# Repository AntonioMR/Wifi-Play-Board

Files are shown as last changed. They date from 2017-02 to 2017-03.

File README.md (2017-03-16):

# Wifi-Play-Board
Placa de experimentacion para el ESP12F (ESP8266)

## Imagenes
Cara superior
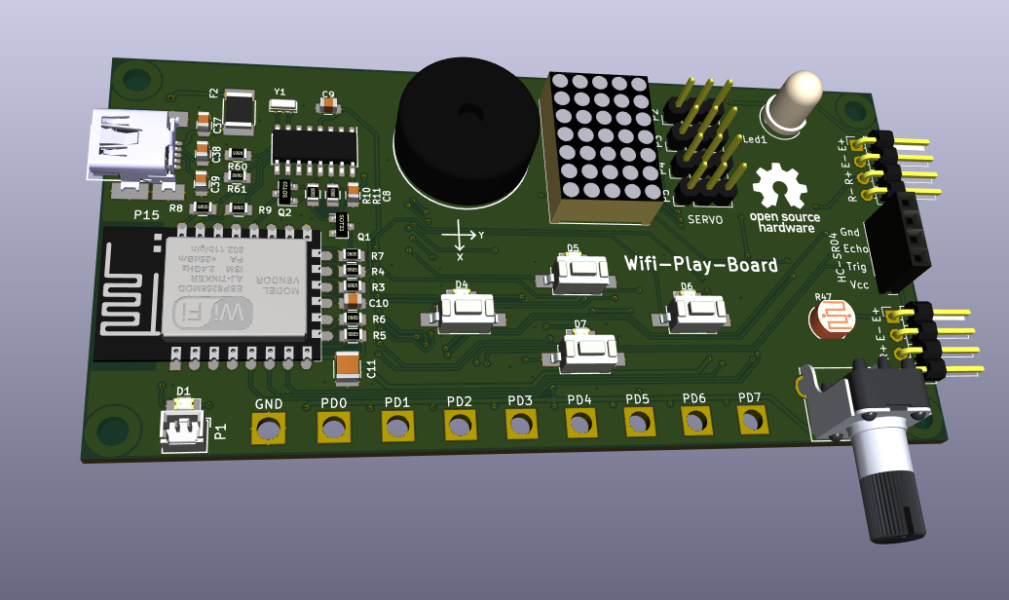
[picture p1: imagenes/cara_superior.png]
Cara superior


Cara inferior
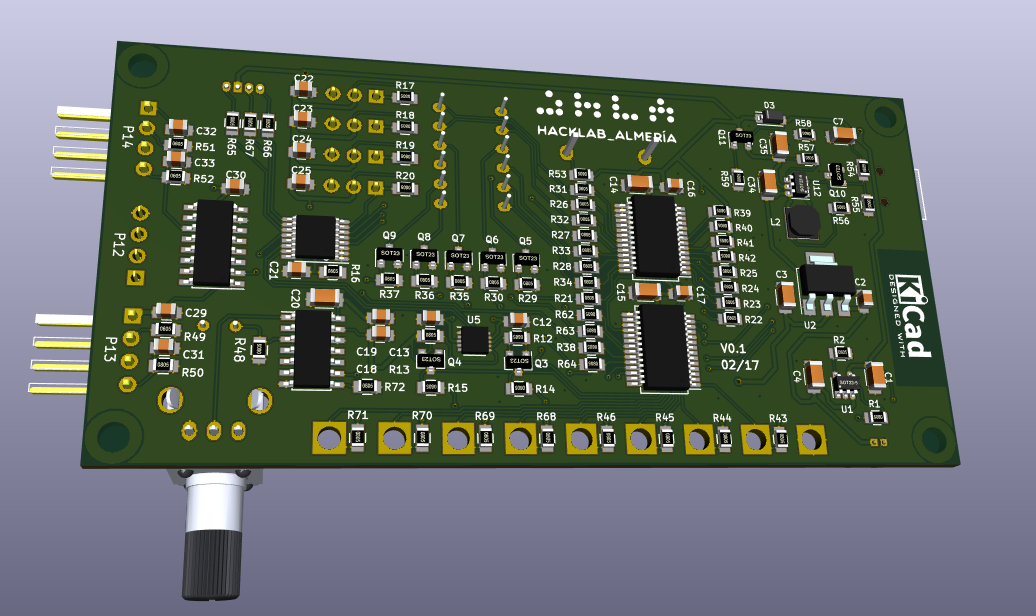
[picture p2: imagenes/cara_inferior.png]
Cara inferior


## Lista de materiales
Refencias | Valor | Total Uds  | Proveedor | ref. Proveedor
----------|-------|------------|-----------|---------------
| R1, R2, R8, R9 | Resistencia 470 Ohm 0805 | 4 | TME | RC0805FR-07470R
| R26, R27, R28, R31, R32, R33, R34, R65, R66, R67 | Resistencia 120 Ohm 0805 | 10 | TME | CRCW0805120RFKTABC
| R38, R49, R51, R62, R63, R64 | Resistencia 220 Ohm 0805 | 6 | TME | RC0805FR-07220R
| R43, R44, R45, R46, R68, R69, R70, R71 | Resistencia 1 MOhm 0805 | 8 | TME | CRCW080510K0FKEA
| R21, R22, R23, R24, R25, R48, R54 | Resistencia 1 KOhm 0805 | 7 | TME | CRCW08051K00FKEA
| R12, R13, R14, R15 | Resistencia 4,7 KOhm 0805 | 4 | TME | CRCW08054K70FKEA
| R29, R30, R35, R36, R37, R50, R52, R55, R72 | Resistencia 47 KOhm 0805 | 9 | TME | CRCW080547K0FKEA
| R10, R11, R16, R17, R18, R19, R20, R3, R39, R4, R40, R41, R42, R5, R53, R56, R59, R6, R7 | Resistencia 10 KOhm 0805 | 19 | TME | CRCW080510K0FKEA
| R60, R61 | Resistencia 22 Ohm 0805 | 2 | TME | CRCW080522R0FKEA
| R57 | Resistencia 976 KOhm 0805 | 1 | RS | 708-7023
| R58 | Resistencia 309 KOhm 0805 | 1 | RS | 708-6871
| C1, C14, C15, C20, C34, C4 | Condensador cerámico 4,7 uF 1206 | 6 | TME | CL31F475ZOFNNNE
| C10 | Condensador cerámico 470 pF 0805 | 1 | TME | CL21B471KBANNND
| C11 | Condensador cerámico 100 uF 1206 | 1 | TME | CL31A107MQHNNNE
| C12, C13, C16, C17, C18, C19, C2, C21, C29, C30, C32, C8, C9 | Condensador cerámico 100 nF 0805 | 13 | TME | CL21B104KBCNNNC
| C22, C23, C24, C25 | Condensador cerámico 1 nF 0805 | 4 | TME | CL21B105KAFNNNE
| C3, C35, C7 | Condensador cerámico 10 uF 1206 | 3 | TME | CL31B103KBCNNNC
| C31, C33, C37 | Condensador cerámico 10 nF 0805 | 3 | TME | CL21B103JBANNNC
| C38, C39 | Condensador cerámico 47 pF 0805 | 2 | TME | CL21C470JBANNNC
| D1, D4, D5, D6, D7 | Diodo LED rojo 0805 | 5 | TME | OSR50805C1E
| D3 | Diodo schottky SOD-123 | 1 | TME | MBR0520L
| F2 | Fusible rearmable 500 mA 1812 | 1 | TME | SD050-16
| L2 | Inductor bobinado 4,7 uH | 1 | RS | 850-7445
| Led1 | LED RGB ánodo común 5mm | 1 | TME | OSTAMA5B31A
| P1 | Conector Molex Picoblade macho recto | 1 | RS | 279-9213
| P13, P14 | Conector Molex Picoblade macho recto | 2 | TME | ZL211-40KG-S
| P15 | Conector USB mini hembra | 1 | TME | MX-67503-1020
| Q1 Q2 Q5 Q6 Q7 Q8 Q9 | Transistor bipolar NPN SOT-23 | 7 | TME | SMBT3904E6327
| Q10 | Transistor bipolar NPN SOT-23 | 1 | TME | BC849CLT1G
| Q11 | Transistor Mosfet P SOT-23 | 1 | TME | NX2301P.215
| Q3, Q4 | Transistor Mosfet P SOT-23 | 1 | TME | BSS138P.215
| BZ1 | Buzzer raster 10 mm | 1 | TME | LD-BZPN-1705
| R47 | Resistencia LDR 5-10 KOhm| 1 | TME | GM4516
| RV1 | Potenciometro lineal 10 KOhm| 1 | RS | 729-3622
| SW1, SW2, SW3, SW4 | Pulsador NO | 4 | TME | DTSM31NB
| U1 | Controlador carga bateria LIPO MCP73831T SOT23-5 | 1 | RS | 738-6617
| U2 | Regulador de tension 3,3V LD1117S33TR SOT23-5 | 1 | RS | LD1117S33TR
| U3 | Conversor USB-Serie CH340G SOIC-16 | 1 |   |
| U5 | Acelerometro 3 ejes MMA7660FC DFN-10 | 1 | RS | 801-6873
| U6, U7 | Expansor GPIO I2C MCP23017 SSOP-28 | 2 | RS | 681-1128
| U8 | Expansor ADC SPI MCP3204 SOIC-14 | 1 | TME | MCP3204-CI/SL
| U9 | Driver para LED 8 canales PCA9551 TSSOP-16 | 1 | RS | 510-730
| U10 | Matriz LED 7x5 Anodo Filas | 1 | TME | KWM-20571ASB
| U11 | Inversor Schmitt trigger | 1 | TME | HEF40106BT
| U12 | Regulador Boost regulable | 1 | RS | 738-6257
| Y1 | Cristal 12 MHHz | 1 | RS | 526-6148

## Licencia
Este diseño es Software Libre; usted puede redistribuirlo y/o modificarlo bajo los términos de la "GNU General Public License" como lo publica la "FSF Free Software Foundation", o (a su elección) de cualquier versión posterior.

Este diseño es distribuido con la esperanza de que le sea útil, pero SIN NINGUNA GARANTIA; incluso sin la garantía implícita por la VENTA o EJERCICIO DE ALGUN PROPOSITO en particular. Vea la "GNU General Public License" para más detalles.

## Creditos
Los modelos 3D de los siguientes componentes están creados a partir de los modelos originales indicados a continuación:

Componente | Autor | Modelo 
-----------|-------|--------
|  |  | 
|  |  | 
|  |  |

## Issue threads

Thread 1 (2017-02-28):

La huella de U11 no corresponde

AntonioMR, 2017-02-28:
En la version V0.1.0 se ha utilizado una huella para SOIC16 cuando el encapsulado es un SOIC14.
En necesario realizar puentes de forma externa para que pueda funcionar esta PCB.
Pendiente de corregir en la siguientes revision

AntonioMR, 2017-03-03:
Corregido en la version V0.1.1

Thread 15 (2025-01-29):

ae:a4:a0:97:82:da need wifi password

Yuhantangonan, 2025-01-29:
ae:a4:a0:97:82:da
Need wifi password

Bahtiar-cyber, 2025-02-11:
da:F1:38:C8:32:0B butuh kata sandinya

valon862, 2025-03-12:
1E:66:32:E7:F0:AD

valon862, 2025-03-12:
> 1E:66:32:E7:F0:AD

Need pasword

Abdullahpunya, 2025-03-22:
2e:16:b4:65:8d:94  Need pasword

ismail690-creator, 2025-04-06:
Butuh kata sandi

ismail690-creator, 2025-04-06:
a8:98:92:3b:42:07 butuh kata sandi

name09651, 2025-04-08:
https://github.com/AntonioMR/Wifi-Play-Board/issues/15

name09651, 2025-04-08:
ae:a4:a0:97:82:da necesito contraseña de wifi #15

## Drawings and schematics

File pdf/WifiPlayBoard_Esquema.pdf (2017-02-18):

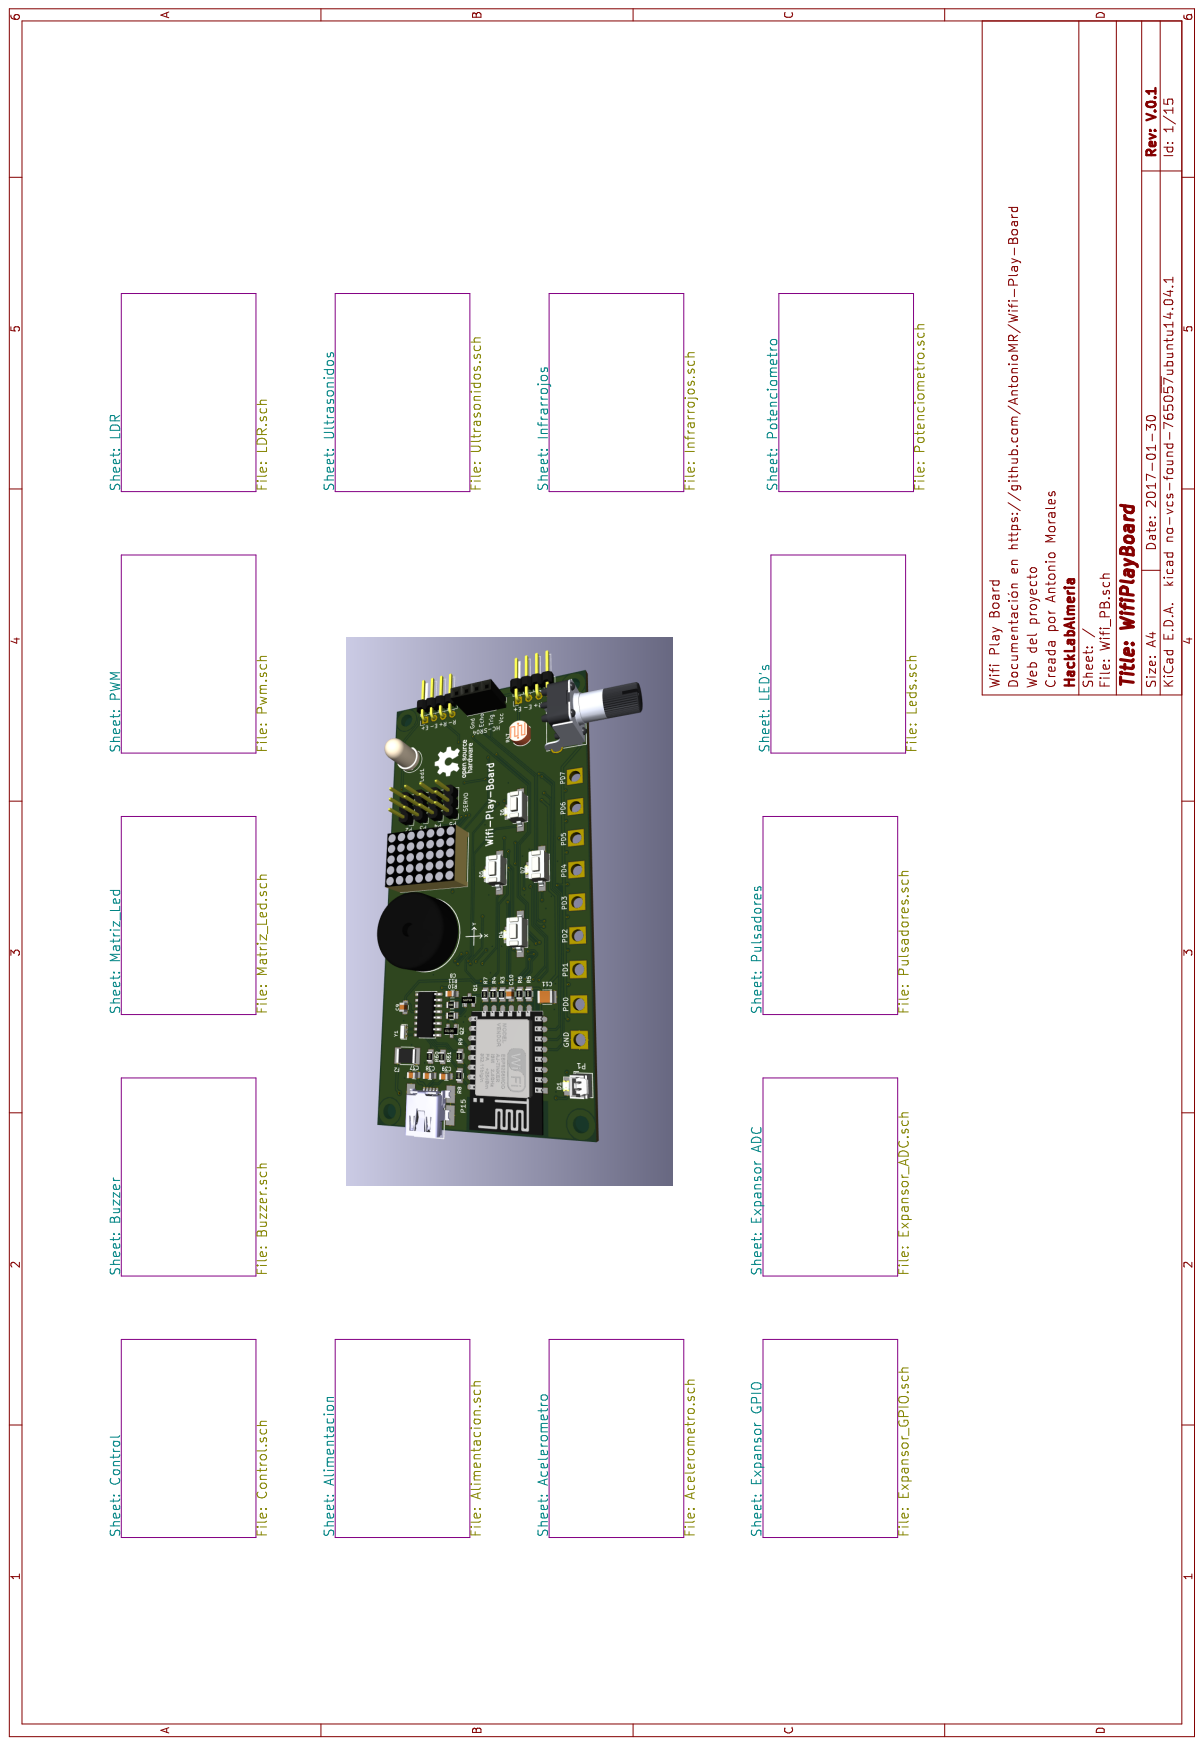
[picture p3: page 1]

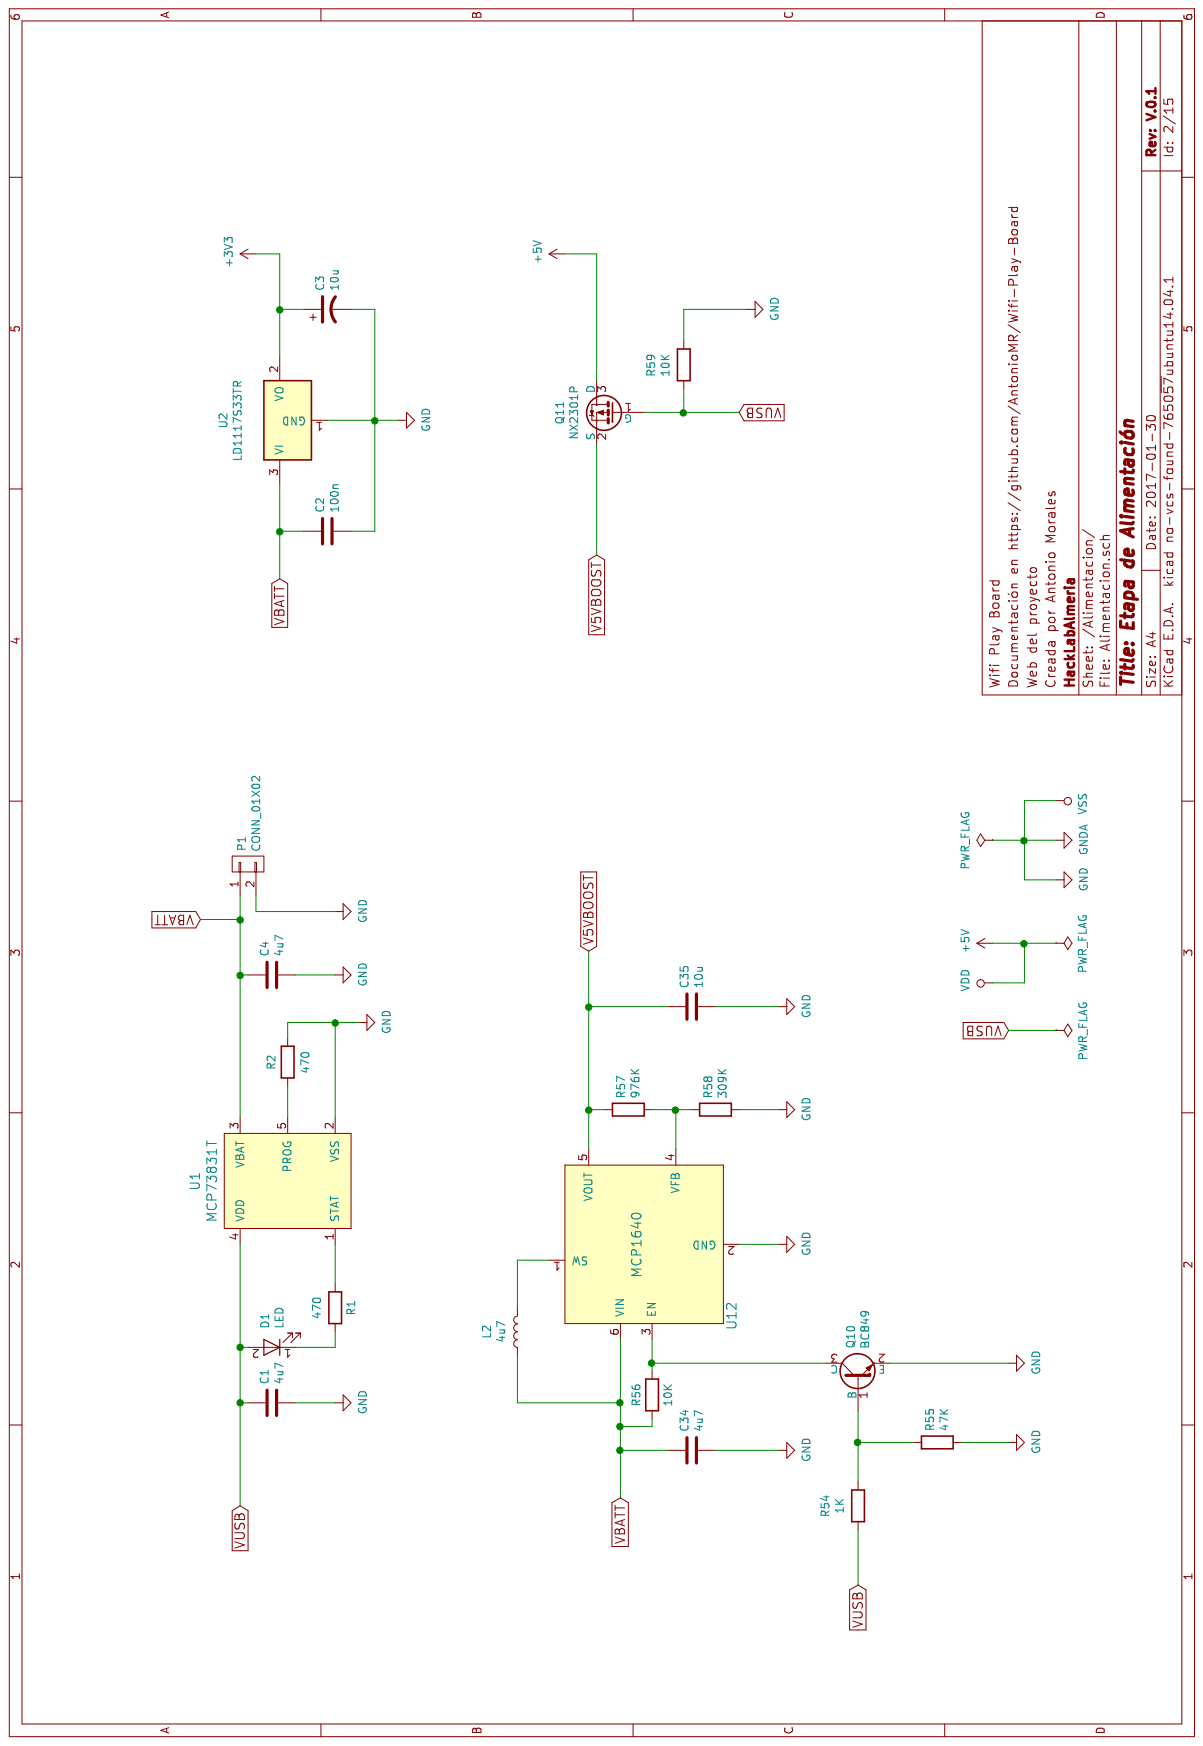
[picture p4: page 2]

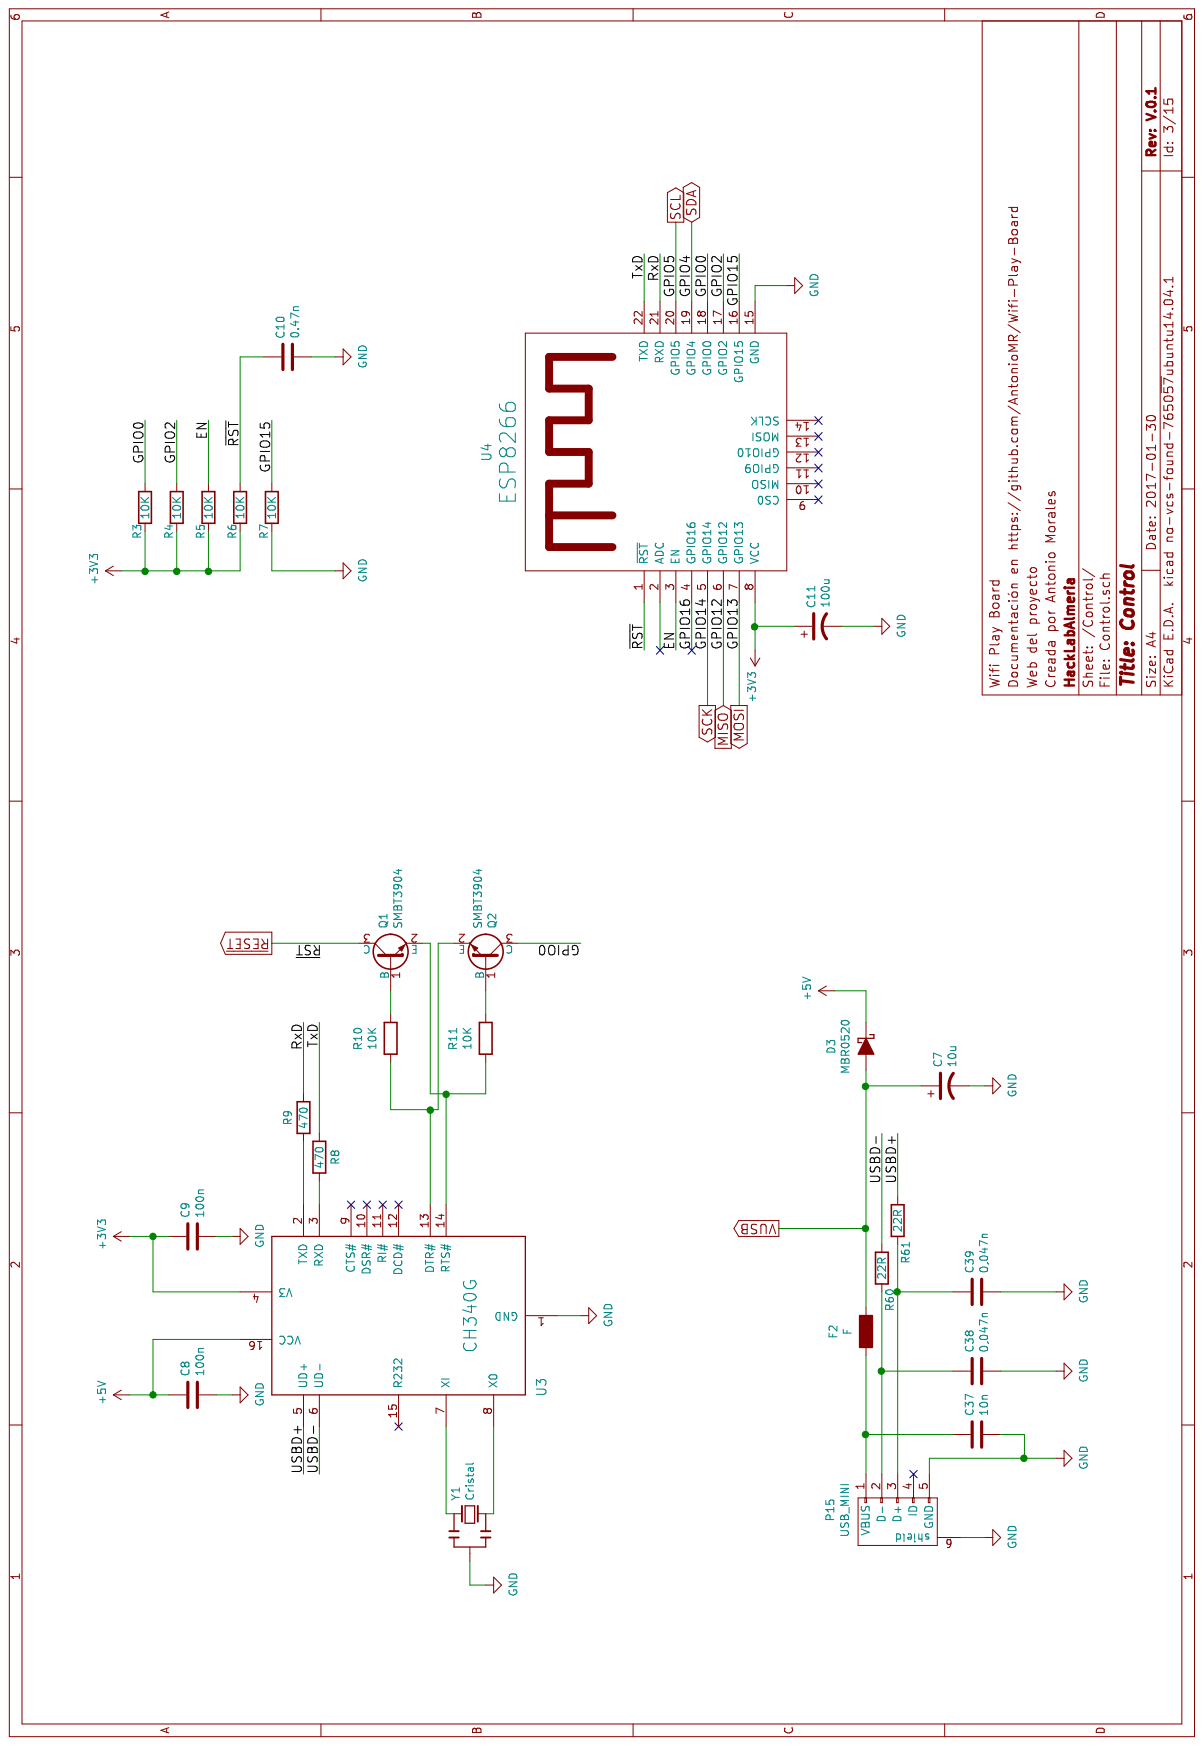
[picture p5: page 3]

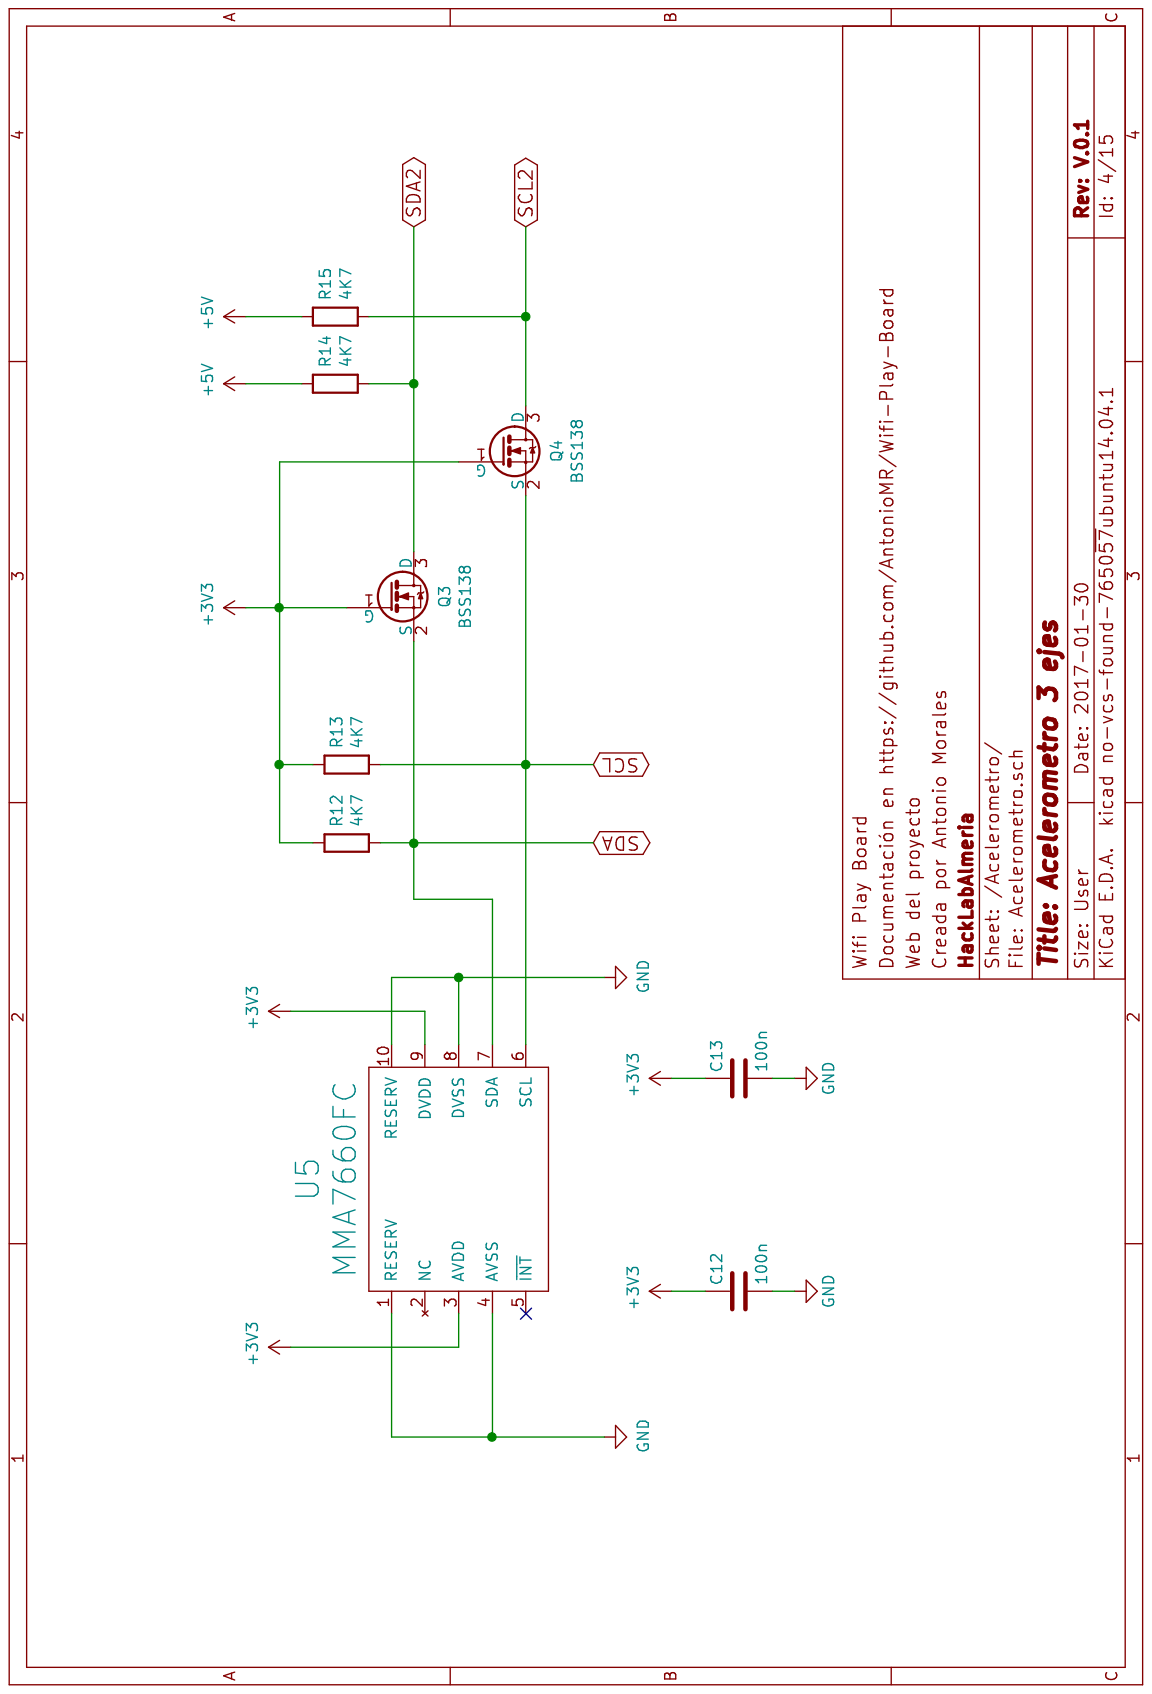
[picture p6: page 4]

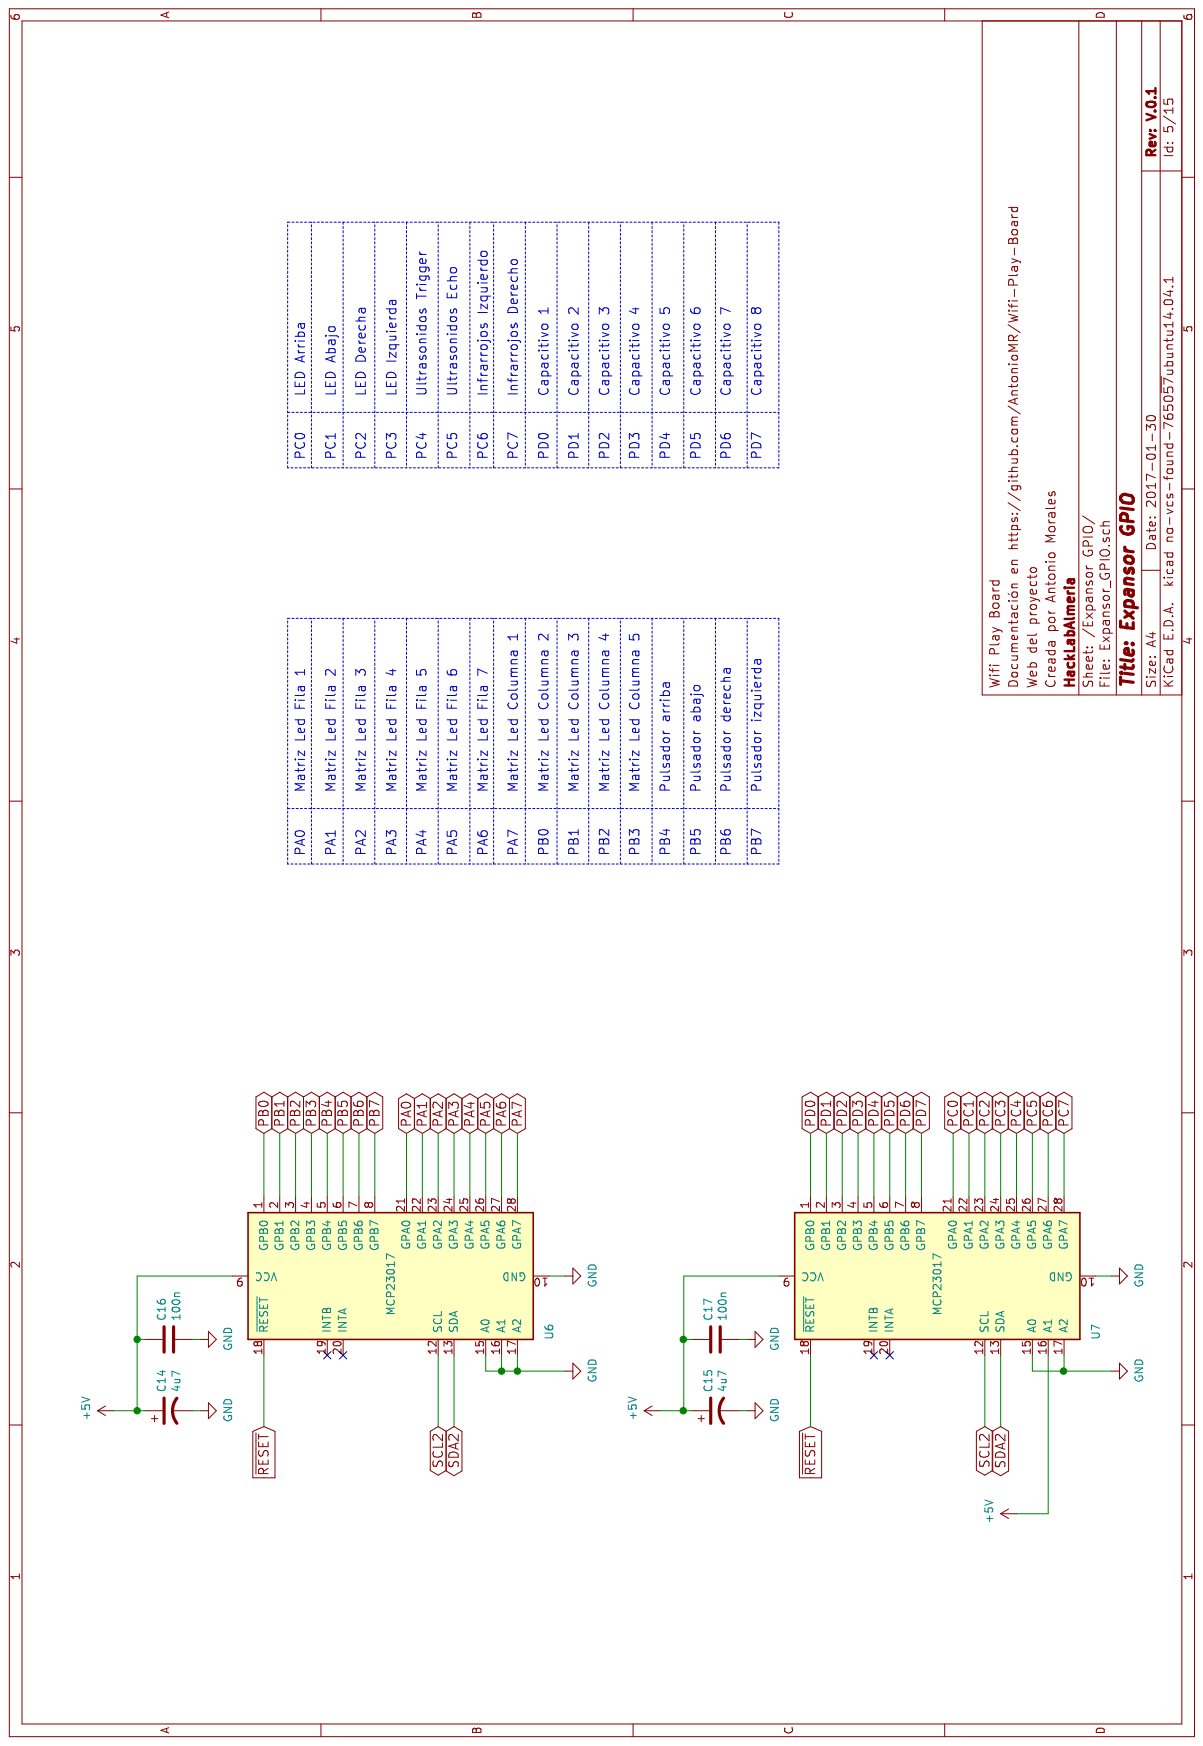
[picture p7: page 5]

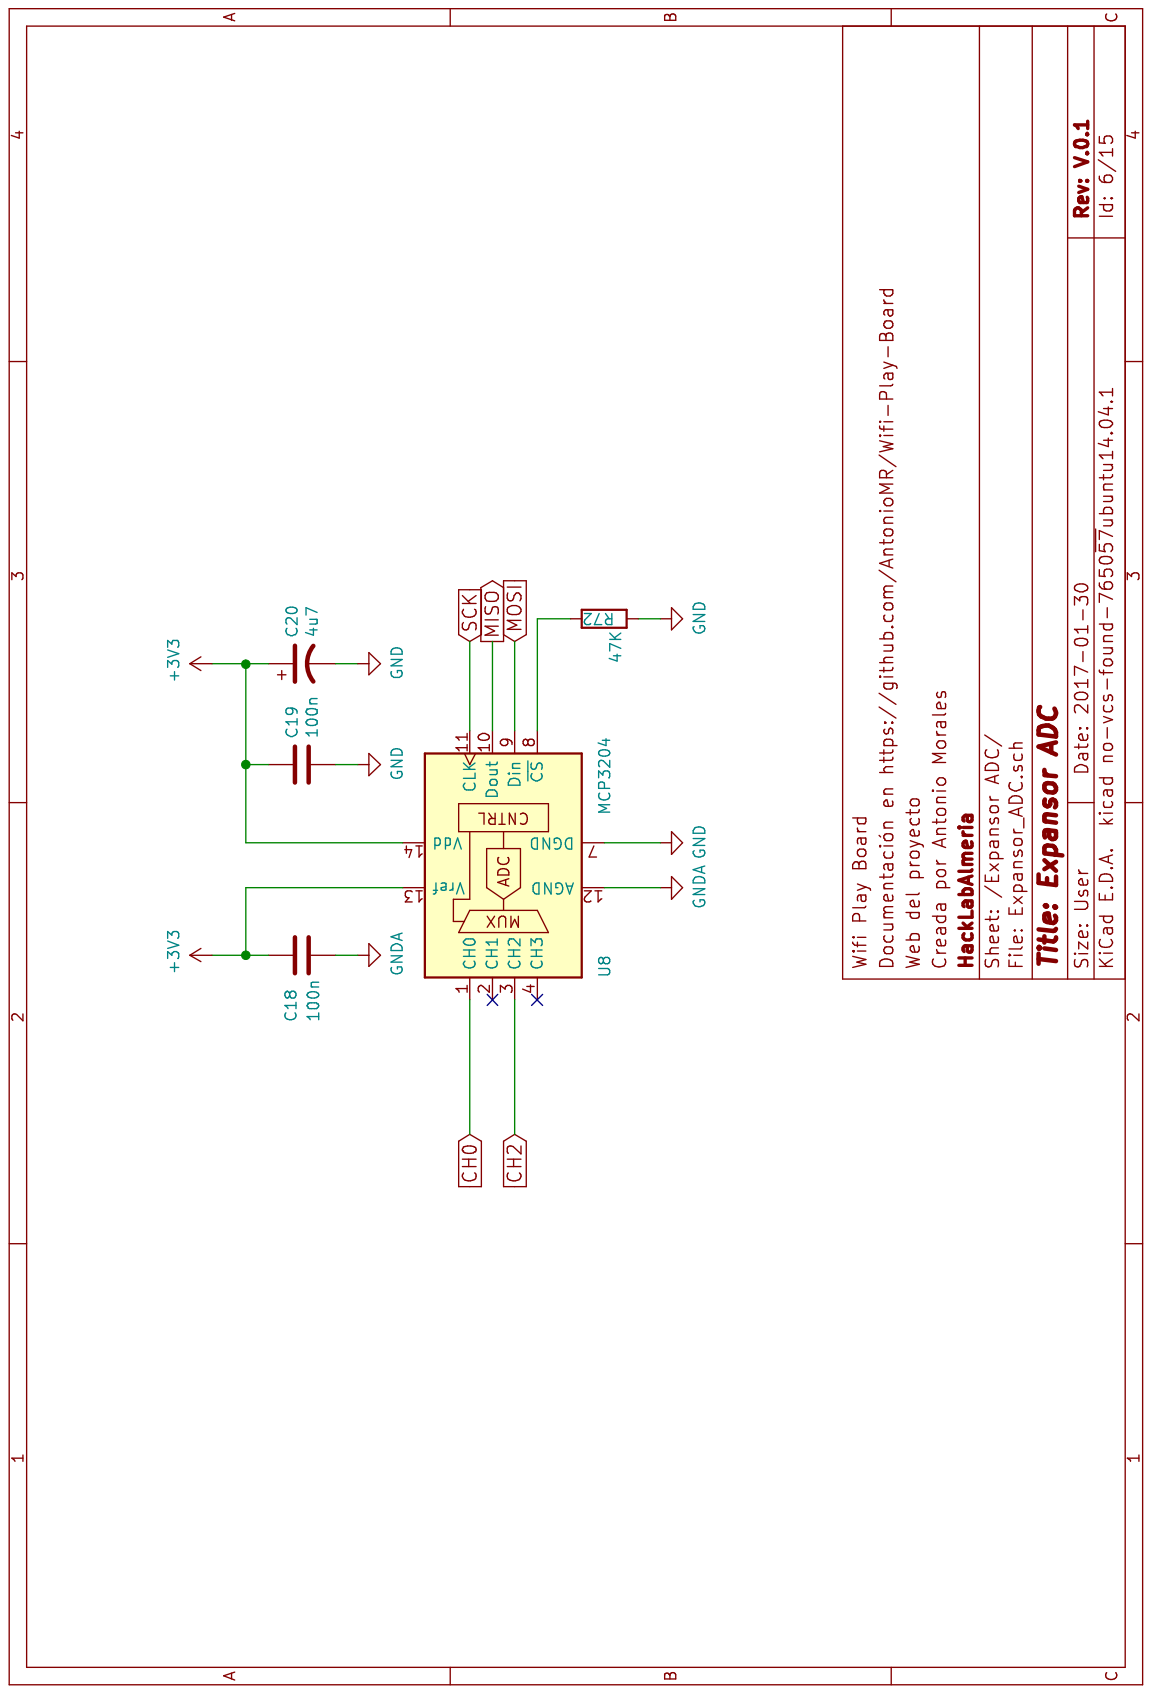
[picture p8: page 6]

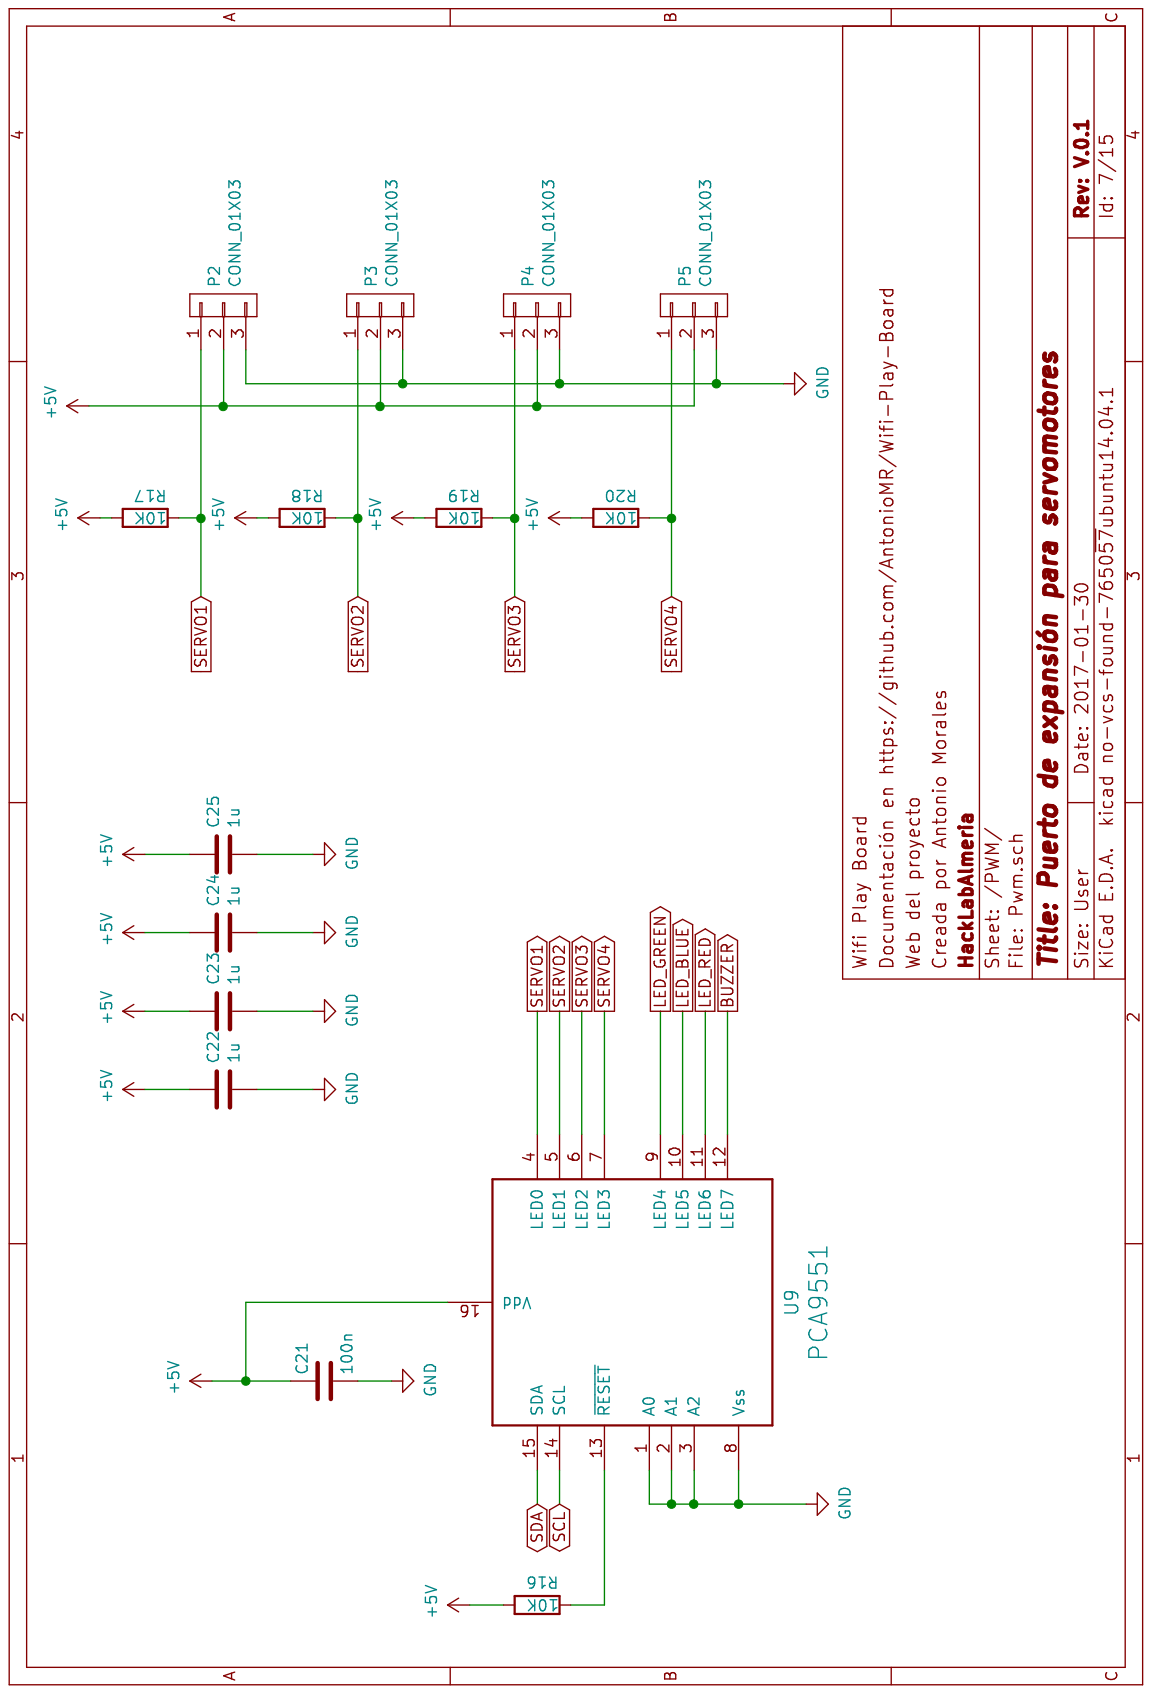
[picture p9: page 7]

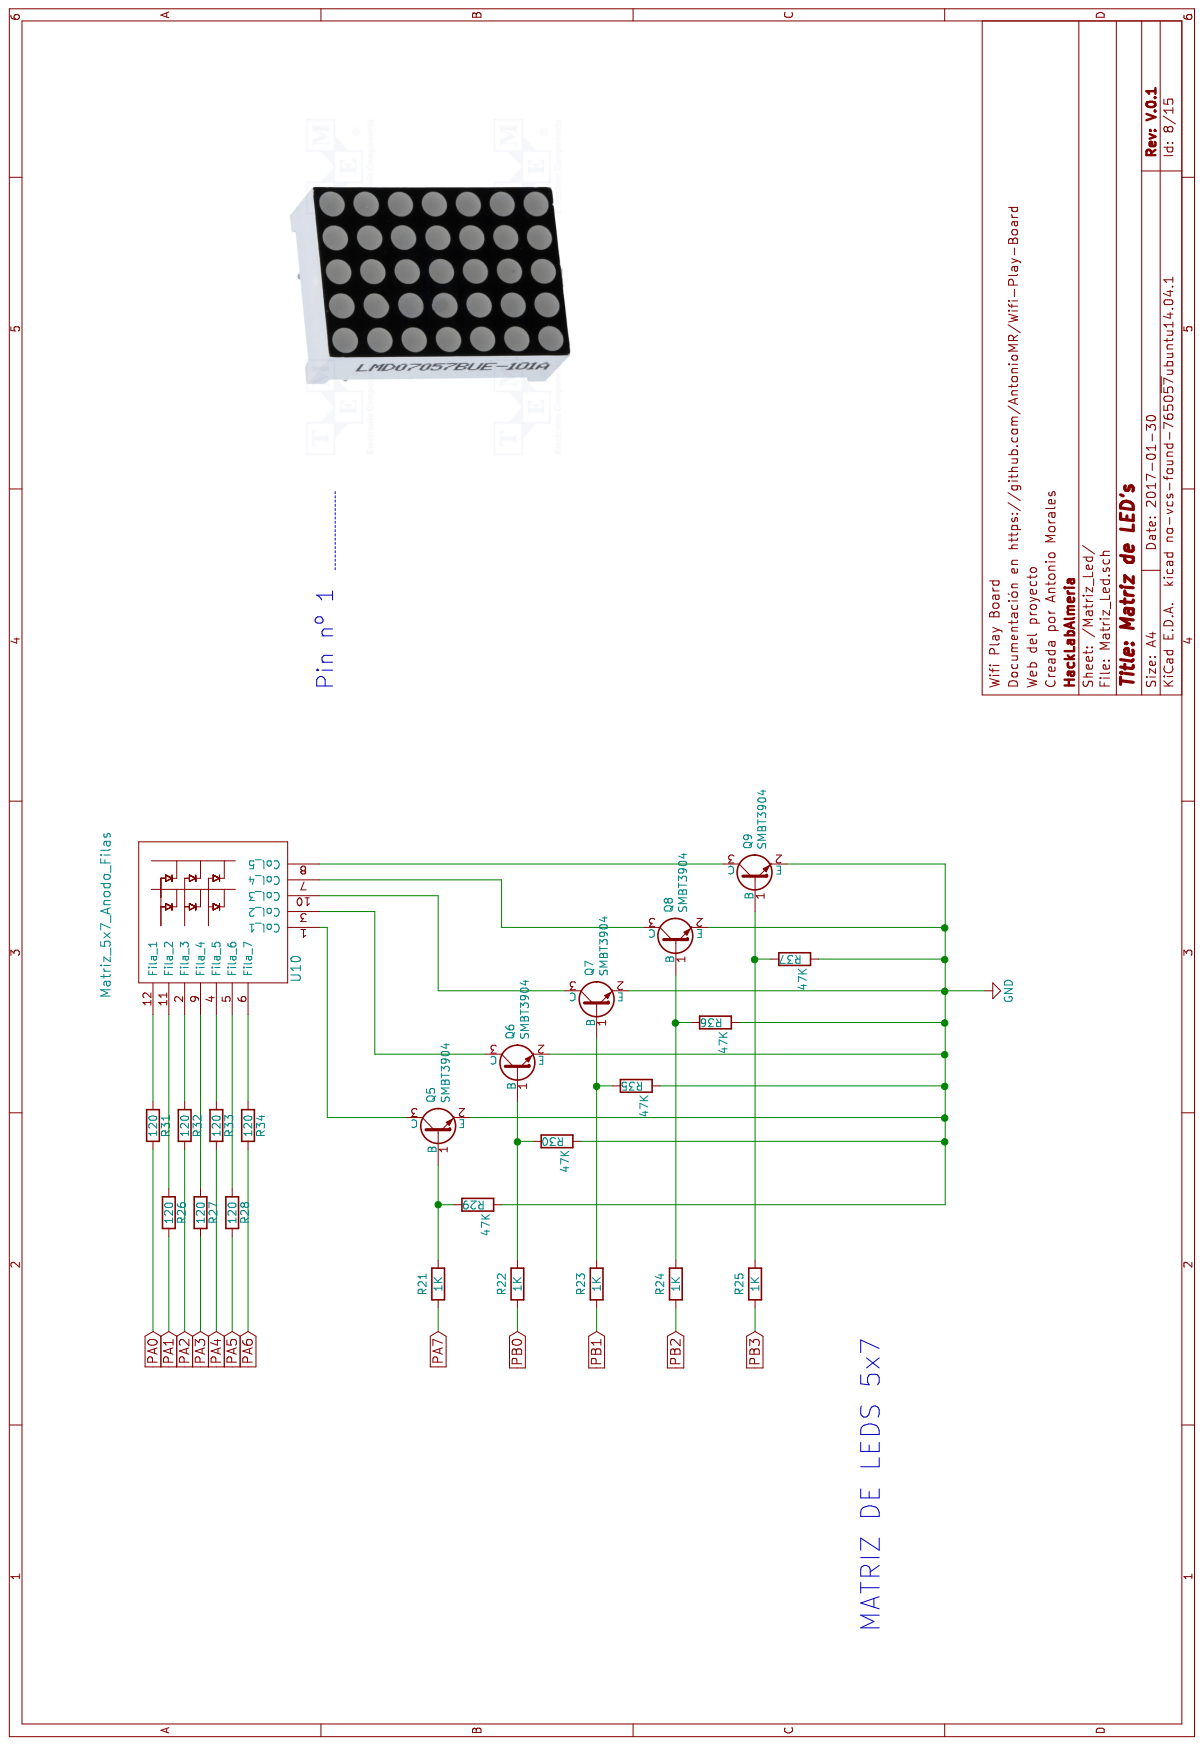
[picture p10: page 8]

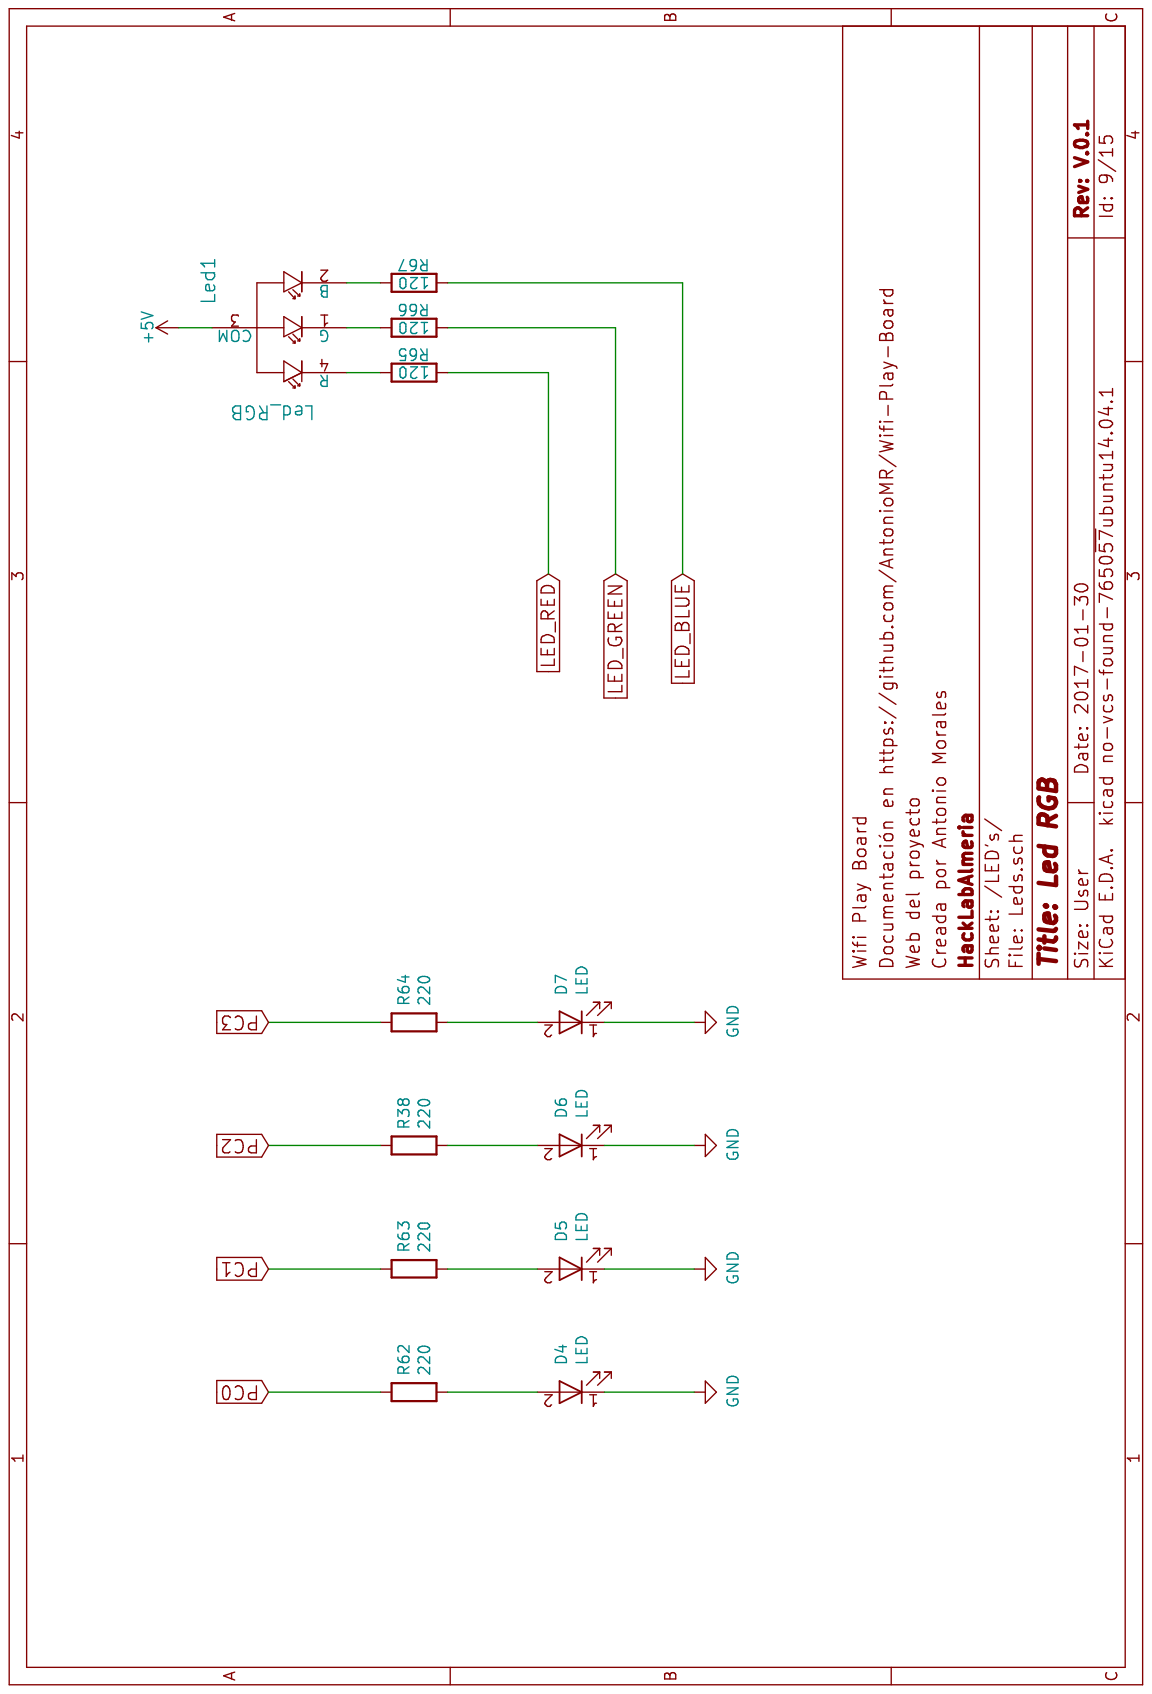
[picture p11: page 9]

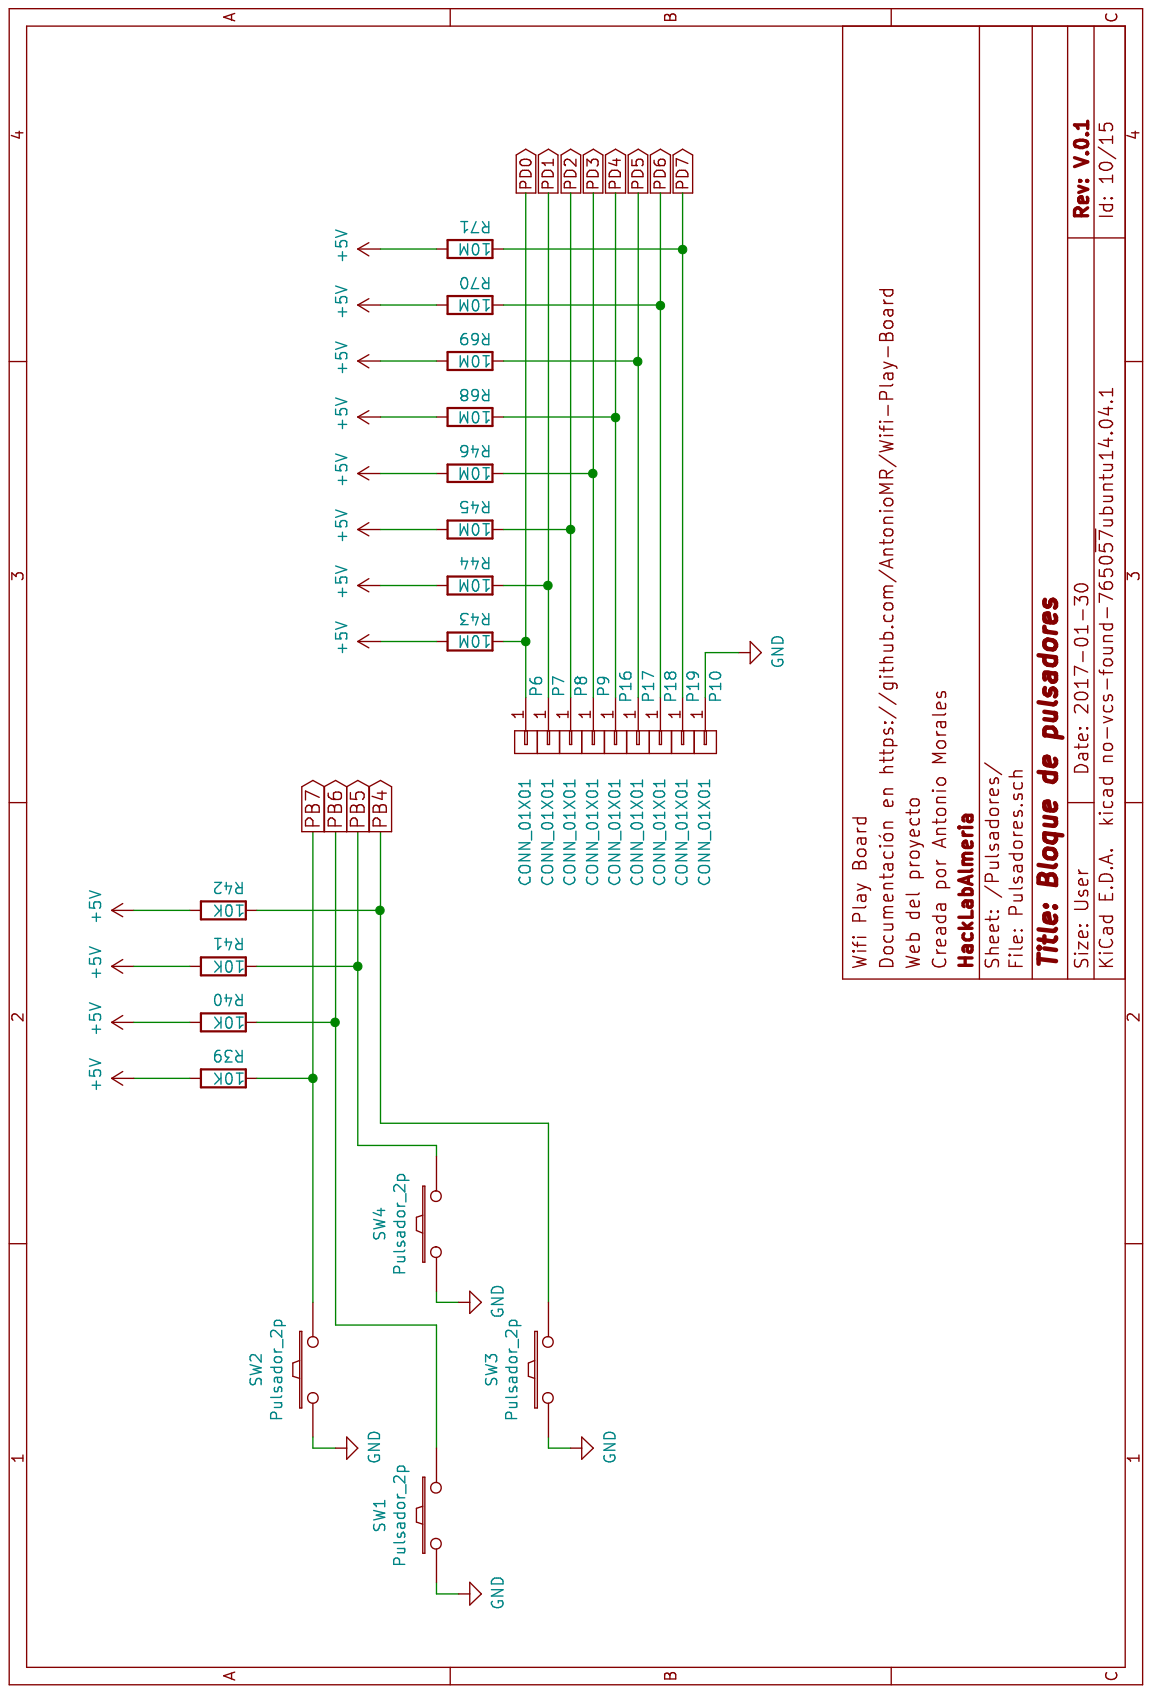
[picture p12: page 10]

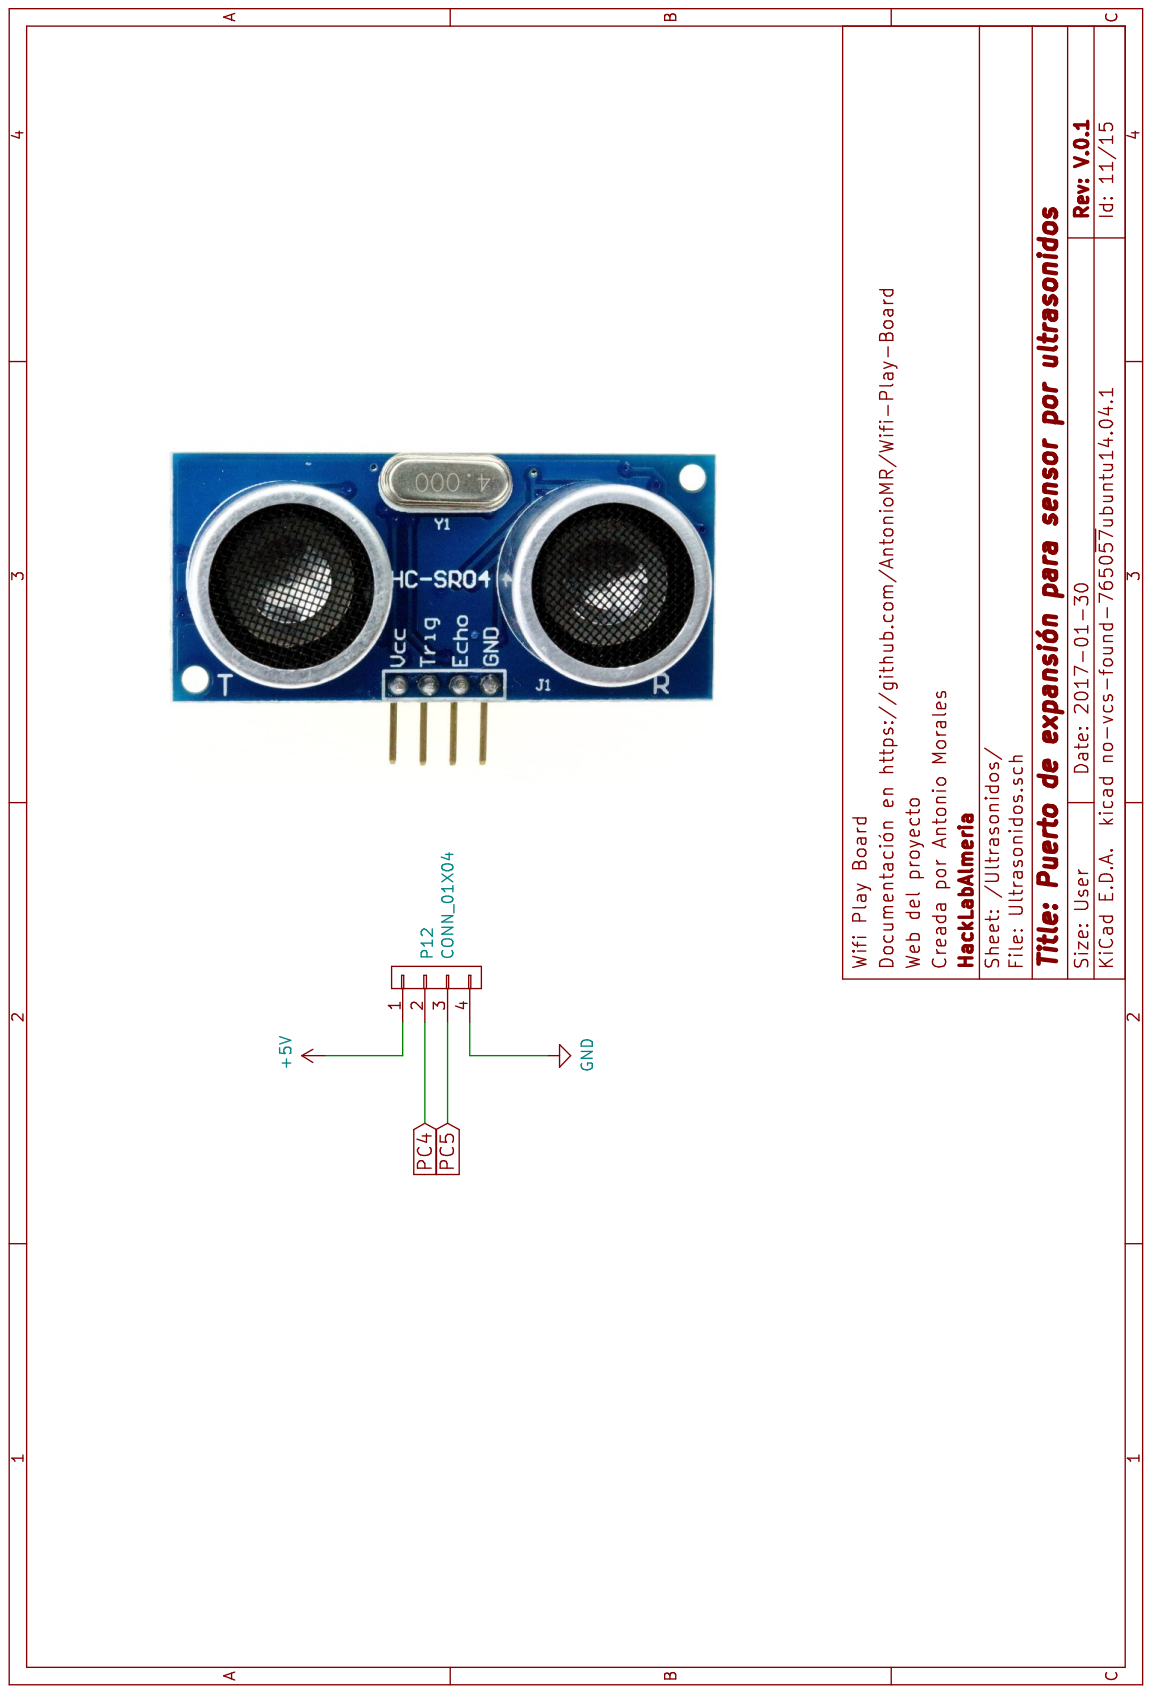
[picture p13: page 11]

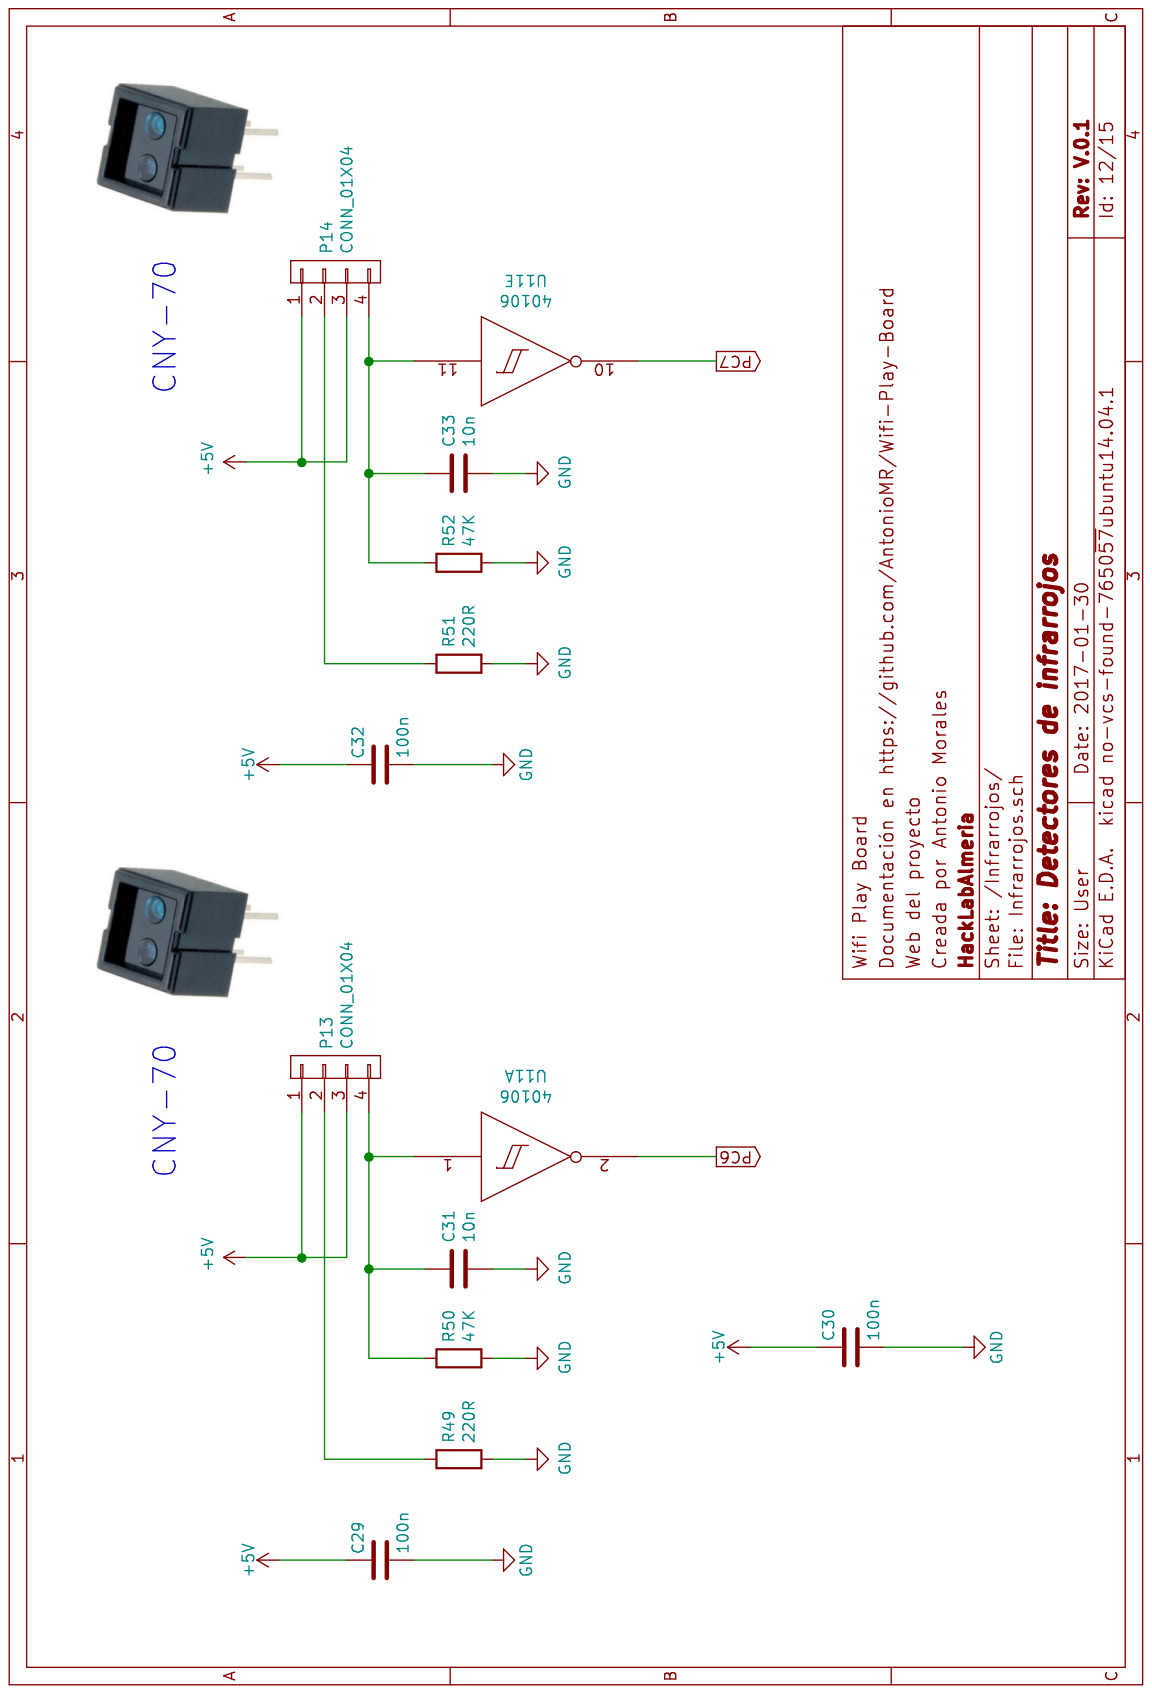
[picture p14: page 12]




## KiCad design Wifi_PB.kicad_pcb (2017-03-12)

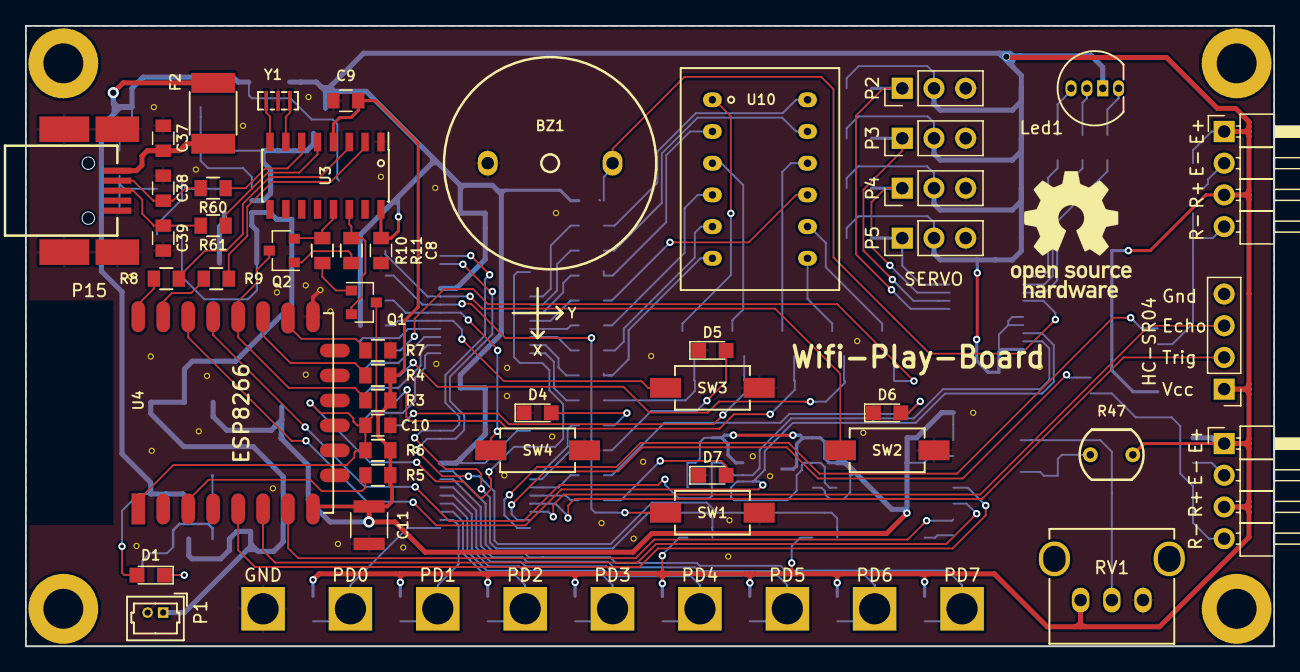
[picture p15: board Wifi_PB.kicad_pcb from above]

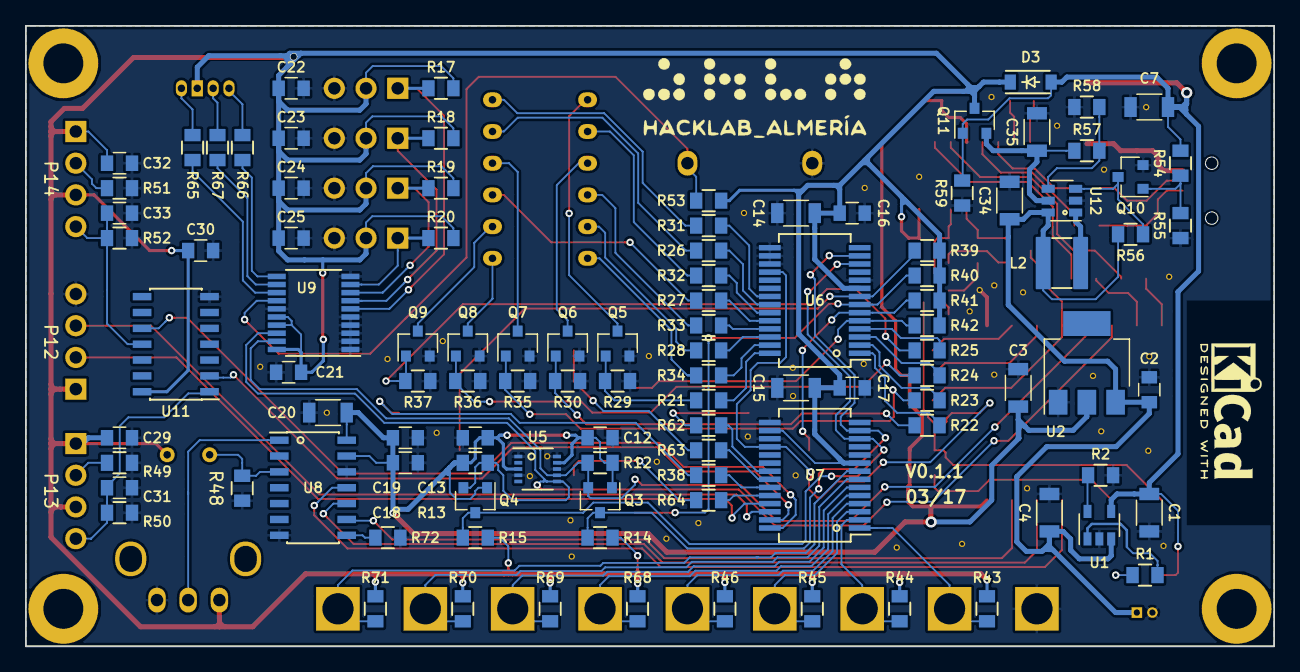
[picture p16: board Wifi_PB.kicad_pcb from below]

Board: 2 copper layers, 100.0 x 49.7 mm, 200 parts (105 on the bottom side), 111 nets.

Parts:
BZ1: Buzzer; LOUDITY_LD-BZPN-1705
C1, C4, C14, C15, C20, C34: 4u7; C_1206
C2, C8, C9, C12, C13, C16, C17, C18, C19, C21, C29, C30, C32: 100n; C_0805
C3, C7, C35: 10u; C_1206
C10: 0.47n; C_0805
C11: 100u; C_1210
C22, C23, C24, C25: 1u; C_0805
C31, C33, C37: 10n; C_0805
C38, C39: 0,047n; C_0805
D1, D4, D5, D6, D7: LED; LED_0805
D3: MBR0520; SOD-123
F2: F; R_1812
Gnd-Via: VAL**; Gnd-Via
Gnd-Via#2, Gnd-Via#3, Gnd-Via#4, Gnd-Via#5, Gnd-Via#6, Gnd-Via#7, Gnd-Via#8, Gnd-Via#9, Gnd-Via#10, Gnd-Via#11, Gnd-Via#12, Gnd-Via#13, Gnd-Via#14, Gnd-Via#15, Gnd-Via#16, Gnd-Via#17, Gnd-Via#18, Gnd-Via#19, Gnd-Via#20, Gnd-Via#21, Gnd-Via#22, Gnd-Via#23, Gnd-Via#24, Gnd-Via#25, Gnd-Via#26, Gnd-Via#27, Gnd-Via#28, Gnd-Via#29, Gnd-Via#30, Gnd-Via#31, Gnd-Via#32, Gnd-Via#33, Gnd-Via#34, Gnd-Via#35, Gnd-Via#36, Gnd-Via#37, Gnd-Via#38, Gnd-Via#39: VAL**; Gnd-Via
L2: 4u7; BOURNS_SRN4012T
Led1: Led_RGB; LED_RGB_5mm_G_B_COM_R_Anodo_comun
P1: CONN_01X02; Molex_PicoBlade_53047-0210_02x1.25mm_Straight
P2, P3, P4, P5: CONN_01X03; Pin_Header_Straight_1x03_Pitch2.54mm
P6, P7, P8, P9, P10, P16, P17, P18, P19: CONN_01X01; Pad_Conector_Cocodrilo
P12: CONN_01X04; Socket_Strip_Straight_1x04_Pitch2.54mm
P13, P14: CONN_01X04; Pin_Header_Angled_1x04_Pitch2.54mm
P15: USB_MINI; usb_mini_molex_675031020
Q1, Q2, Q5, Q6, Q7, Q8, Q9: SMBT3904; SOT-23
Q3, Q4: BSS138; SOT-23
Q10: BC849; SOT-23
Q11: NX2301P; SOT-23
R1, R2, R8, R9: 470; R_0805
R3, R4, R5, R6, R7, R10, R11, R17, R18, R19, R20, R39, R40, R41, R42, R53, R56, R59: 10K; R_0805
R12, R13, R14, R15: 4K7; R_0805
R21, R22, R23, R24, R25, R48, R54: 1K; R_0805
R26, R27, R28, R31, R32, R33, R34, R65, R66, R67: 120; R_0805
R29, R30, R35, R36, R37, R50, R52, R55, R72: 47K; R_0805
R38, R62, R63, R64: 220; R_0805
R43, R44, R45, R46, R68, R69, R70, R71: 10M; R_0805
R47: LDR; LDR_TOKEN_PGM5_Series
R49, R51: 220R; R_0805
R57: 976K; R_0805
R58: 309K; R_0805
R60, R61: 22R; R_0805
RV1: POT; ALP_RK09K111
SW1, SW2, SW3, SW4: Pulsador_2p; CANAL_ELECTRONIC_DTSM-31N-B
U1: MCP73831T; SOT-23-5
U2: LD1117S33TR; SOT-223
U3: CH340G; SOIC-16_3.9x9.9mm_Pitch1.27mm
U4: ESP8266; ESP-12E
U5: MMA7660FC; DFN-10-1EP_3x3mm_Pitch0.5mm
U6, U7: MCP23017; SSOP-28_5.3x10.2mm_Pitch0.65mm
U8: MCP3204; SOIC-14_3.9x8.7mm_Pitch1.27mm
U9: PCA9634; TSSOP-20_4.4x6.5mm_Pitch0.65mm
U10: Matriz_5x7_Anodo_Filas; Matriz_Led_7X5
U11: 40106; SOIC-14_3.9x8.7mm_Pitch1.27mm
U12: MCP1640; SOT-23-6
Y1: Cristal; Murata_CSTCE_V_A

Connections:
+3V3: C3.1, C9.1, C11.1, C12.1, C13.1, C18.1, C19.1, C20.1, Q3.1, Q4.1, R3.2, R4.2, R5.2, R6.2, R12.1, R13.1, U2.2, U3.4, U4.8, U5.3, U5.9, U8.13, U8.14
+5V: C8.1, C14.1, C15.1, C16.1, C17.1, C21.1, C22.1, C23.1, C24.1, C25.1, C29.1, C30.1, C32.1, D3.1, Led1.3, P2.2, P3.2, P4.2, P5.2, P12.1, P13.1, P13.3, P14.1, P14.3, Q11.3, R14.1, R15.1, R17.1, R18.1, R19.1, R20.1, R39.1, R40.1, R41.1, R42.1, R43.1, R44.1, R45.1, R46.1, R47.1, R53.1, R68.1, R69.1, R70.1, R71.1, RV1.1, U3.16, U6.9, U7.9, U7.16, U9.16, U9.17, U9.20, U11.14
/Control/EN: R5.1, U4.3
/Control/GPIO0: Q2.3, R3.1, U4.18
/Control/GPIO2: R4.1, U4.17
/Control/GPIO15: R7.1, U4.16
/Control/RxD: R9.1, U4.21
/Control/TxD: R8.1, U4.22
/Control/USBD+: R61.1, U3.5
/Control/USBD-: R60.1, U3.6
BUZZER: BZ1.1, R53.2, U9.14
CH0: RV1.2, U8.1
CH2: R47.2, R48.2, U8.3
GND: BZ1.2, C1.2, C2.2, C3.2, C4.2, C7.2, C8.2, C9.2, C10.2, C11.2, C12.2, C13.2, C14.2, C15.2, C16.2, C17.2, C18.2, C19.2, C20.2, C21.2, C22.2, C23.2, C24.2, C25.2, C29.2, C30.2, C31.2, C32.2, C33.2, C34.2, C35.2, C37.2, C38.2, C39.2, D4.1, D5.1, D6.1, D7.1, Gnd-Via.1, Gnd-Via#2.1, Gnd-Via#3.1, Gnd-Via#4.1, Gnd-Via#5.1, Gnd-Via#6.1, Gnd-Via#7.1, Gnd-Via#8.1, Gnd-Via#9.1, Gnd-Via#10.1, Gnd-Via#11.1, Gnd-Via#12.1, Gnd-Via#13.1, Gnd-Via#14.1, Gnd-Via#15.1, Gnd-Via#16.1, Gnd-Via#17.1, Gnd-Via#18.1, Gnd-Via#19.1, Gnd-Via#20.1, Gnd-Via#21.1, Gnd-Via#22.1, Gnd-Via#23.1, Gnd-Via#24.1, Gnd-Via#25.1, Gnd-Via#26.1, Gnd-Via#27.1, Gnd-Via#28.1, Gnd-Via#29.1, Gnd-Via#30.1, Gnd-Via#31.1, Gnd-Via#32.1, Gnd-Via#33.1, Gnd-Via#34.1, Gnd-Via#35.1, Gnd-Via#36.1, Gnd-Via#37.1, Gnd-Via#38.1, Gnd-Via#39.1, P1.2, P2.3, P3.3, P4.3, P5.3, P10.1, P12.4, P15.5, P15.6, Q5.2, Q6.2, Q7.2, Q8.2, Q9.2, Q10.2, R2.2, R7.2, R29.2, R30.2, R35.2, R36.2, R37.2, R48.1, R49.2, R50.2, R51.2, R52.2, R55.2, R58.2, R59.1, R72.2, RV1.3, SW1.1, SW2.1, SW3.1, SW4.1, U1.2, U2.1, U3.1, U4.15, U5.1, U5.4, U5.8, U5.10, U6.10, U6.15, U6.16, U6.17, U7.10, U7.15, U7.17, U8.7, U8.12, U9.1, U9.2, U9.3, U9.4, U9.5, U9.10, U9.15, U11.7, U12.2, Y1.2
LED_BLUE: R67.2, U9.12
LED_GREEN: R66.2, U9.11
LED_RED: R65.2, U9.13
MISO: U4.6, U8.10
MOSI: U4.7, U8.9
unnamed: C31.1, P13.4, R50.1, U11.1
unnamed: C33.1, P14.4, R52.1, U11.11
unnamed: C37.1, F2.2, P15.1
unnamed: C38.1, P15.2, R60.2
unnamed: C39.1, P15.3, R61.2
unnamed: D1.1, R1.2
unnamed: D4.2, R62.2
unnamed: D5.2, R63.2
unnamed: D6.2, R38.2
unnamed: D7.2, R64.2
unnamed: L2.2, U12.1
unnamed: Led1.1, R66.1
unnamed: Led1.2, R67.1
unnamed: Led1.4, R65.1
unnamed: P13.2, R49.1
unnamed: P14.2, R51.1
unnamed: Q1.1, R10.1
unnamed: Q1.2, R11.2, U3.14
unnamed: Q2.1, R11.1
unnamed: Q2.2, R10.2, U3.13
unnamed: Q5.1, R21.1, R29.1
unnamed: Q5.3, U10.1
unnamed: Q6.1, R22.1, R30.1
unnamed: Q6.3, U10.3
unnamed: Q7.1, R23.1, R35.1
unnamed: Q7.3, U10.10
unnamed: Q8.1, R24.1, R36.1
unnamed: Q8.3, U10.7
unnamed: Q9.1, R25.1, R37.1
unnamed: Q9.3, U10.8
unnamed: Q10.1, R54.1, R55.1
unnamed: Q10.3, R56.1, U12.3
unnamed: R1.1, U1.1
unnamed: R2.1, U1.5
unnamed: R8.2, U3.3
unnamed: R9.2, U3.2
unnamed: R26.1, U10.11
unnamed: R27.1, U10.9
unnamed: R28.1, U10.5
unnamed: R31.1, U10.12
unnamed: R32.1, U10.2
unnamed: R33.1, U10.4
unnamed: R34.1, U10.6
unnamed: R57.2, R58.1, U12.4
unnamed: R72.1, U8.8
unnamed: U3.7, Y1.1
unnamed: U3.8, Y1.3
PA0: R31.2, U6.21
PA1: R26.2, U6.22
PA2: R32.2, U6.23
PA3: R27.2, U6.24
PA4: R33.2, U6.25
PA5: R28.2, U6.26
PA6: R34.2, U6.27
PA7: R21.2, U6.28
PB0: R22.2, U6.1
PB1: R23.2, U6.2
PB2: R24.2, U6.3
PB3: R25.2, U6.4
PB4: R42.2, SW3.2, U6.5
PB5: R41.2, SW4.2, U6.6
PB6: R40.2, SW1.2, U6.7
PB7: R39.2, SW2.2, U6.8
PC0: R62.1, U7.21
PC1: R63.1, U7.22
PC2: R38.1, U7.23
PC3: R64.1, U7.24
PC4: P12.2, U7.25
PC5: P12.3, U7.26
PC6: U7.27, U11.2
PC7: U7.28, U11.10
PD0: P6.1, R43.2, U7.1
PD1: P7.1, R44.2, U7.2
PD2: P8.1, R45.2, U7.3
PD3: P9.1, R46.2, U7.4
PD4: P16.1, R68.2, U7.5
PD5: P17.1, R69.2, U7.6
PD6: P18.1, R70.2, U7.7
PD7: P19.1, R71.2, U7.8
SCK: U4.5, U8.11
SCL: Q4.2, R13.2, U4.20, U5.6, U9.18
SCL2: Q4.3, R15.2, U6.12, U7.12
SDA: Q3.2, R12.2, U4.19, U5.7, U9.19
SDA2: Q3.3, R14.2, U6.13, U7.13
SERVO1: P2.1, R17.2, U9.6
SERVO2: P3.1, R18.2, U9.7
SERVO3: P4.1, R19.2, U9.8
SERVO4: P5.1, R20.2, U9.9
V5VBOOST: C35.1, Q11.2, R57.1, U12.5
VBATT: C2.1, C4.1, C34.1, L2.1, P1.1, R56.2, U1.3, U2.3, U12.6
VUSB: C1.1, C7.1, D1.2, D3.2, F2.1, Q11.1, R54.2, R59.2, U1.4
~RESET: C10.1, Q1.3, R6.1, U4.1, U6.18, U7.18

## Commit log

2017-01-15 carga inicial proyecto y hojas del esquema
    [Acelerometro.sch, Alimentacion.sch, Conectores_E_S.sch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]
2017-01-30 version preliminar de la etapa de alimentacion
    [Acelerometro.sch, Alimentacion.sch, Buzzer.sch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]
2017-02-03 asignacion inicial de huellas
    [Acelerometro.sch, Alimentacion.sch, Buzzer.sch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]
2017-02-04 cambiar ch340T por ch340g y añadir nc a pines
    [Acelerometro.sch, Alimentacion.sch, Buzzer.sch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]
2017-02-04 cambiado cristal de cuarzo por resonador
    [Acelerometro.sch, Alimentacion.sch, Buzzer.sch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]
2017-02-05 place inicial sobre la pcb
    [Acelerometro.sch, Alimentacion.sch, Buzzer.sch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]
2017-02-07 ordenar componentes y referencias
    [Acelerometro.sch, Alimentacion.sch, Buzzer.sch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]
2017-02-07 añadir imagenes de la pcb
2017-02-08 realizado el trazado de los reguladores
    [Wifi_PB.kicad_pcb]
2017-02-09 modificado conexion led rgb para mejorar trazado
    [Pwm.sch, Wifi_PB.kicad_pcb]
2017-02-12 añadida LDR. Finalizado trazado provisional
    [Acelerometro.sch, Alimentacion.sch, Buzzer.sch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]
2017-02-12 añadidos logos a la serigrafia
    [Wifi_PB.kicad_pcb]
2017-02-12 conectar reset gpio. retocar plano masa
    [Acelerometro.sch, Alimentacion.sch, Buzzer.sch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]
2017-02-13 girar conector detector ultrasionidos
    [Wifi_PB.kicad_pcb]
2017-02-13 Mejoras en serigrafia
    [Wifi_PB.kicad_pcb]
2017-02-13 finalizada pcb V0.1
    [Wifi_PB.kicad_pcb]
2017-02-13 ajustada margen mascara soldadura a 5 mils
    [Wifi_PB.kicad_pcb]
2017-02-13 correcciones en serigrafias sobre pads
    [Wifi_PB.kicad_pcb]
2017-02-13 version para envio a fabricar, gerber y panel 2x1
    [Wifi_PB-B.Cu.gbl, Wifi_PB-B.Mask.gbs, Wifi_PB-B.Paste.gbp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]
2017-02-13 actualizar imagenes pcb a V0.1
2017-02-15 añadidos valores y referencias a control, alimentacion y gpioEx
    [Alimentacion.sch, Control.sch, Expansor_GPIO.sch]
2017-02-16 actualizadas referencias en componentes y ordenado esquema electrico
    [Acelerometro.sch, Alimentacion.sch, Buzzer.sch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]
2017-02-16 añadidas listas de resistencias al BOM
2017-02-18 añadido BOM al README
2017-02-19 añadidos modelos 3D y referencias relativas a estos en el proyecto
    [Wifi_PB.kicad_pcb]
2017-02-19 error en el modelo 3d del led RGB
    [Wifi_PB.kicad_pcb]
2017-03-03 modificada huella de U7 a SOIC14. Corrige issue #1
    [Acelerometro.sch, Alimentacion.sch, Buzzer.sch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]
2017-03-12 cambiado el driver led al PCA9634
    [Acelerometro.sch, Alimentacion.sch, Buzzer.sch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]
2017-03-16 errata en BOM
